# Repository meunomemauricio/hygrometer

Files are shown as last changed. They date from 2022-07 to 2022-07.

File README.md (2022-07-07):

# Hygrometer

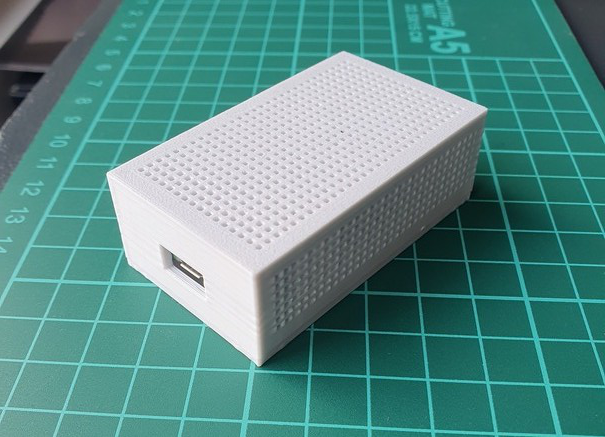
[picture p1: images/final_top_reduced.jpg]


DIY HA compatible Temperature & Humidity Sensor

# 3D Printed Enclosure

## Design

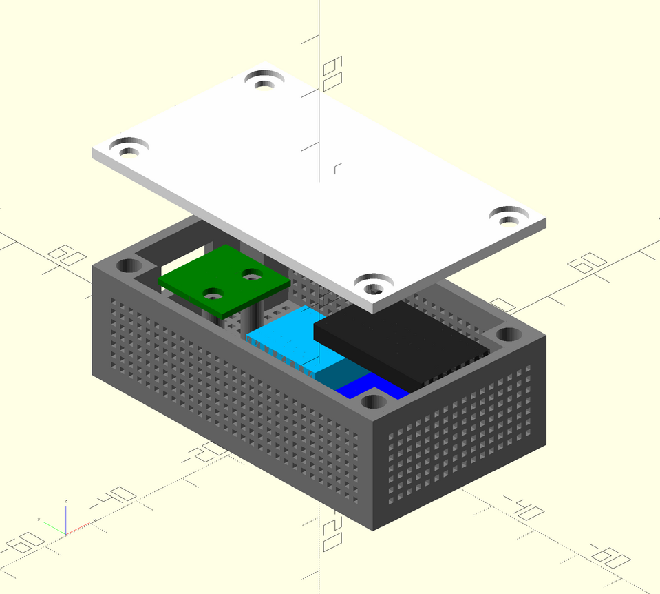
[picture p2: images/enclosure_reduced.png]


## USB Board 

It's better to test if the dimensions of the USB board are correct enough by printing a [simplified support](https://github.com/meunomemauricio/hygrometer/blob/f57ef0650a297ba861d08bb6003e8ca89dd94b08/usb_fit_test.scad).

| Simplified Support |  Board fit
:-------------------:|:-------------------------:
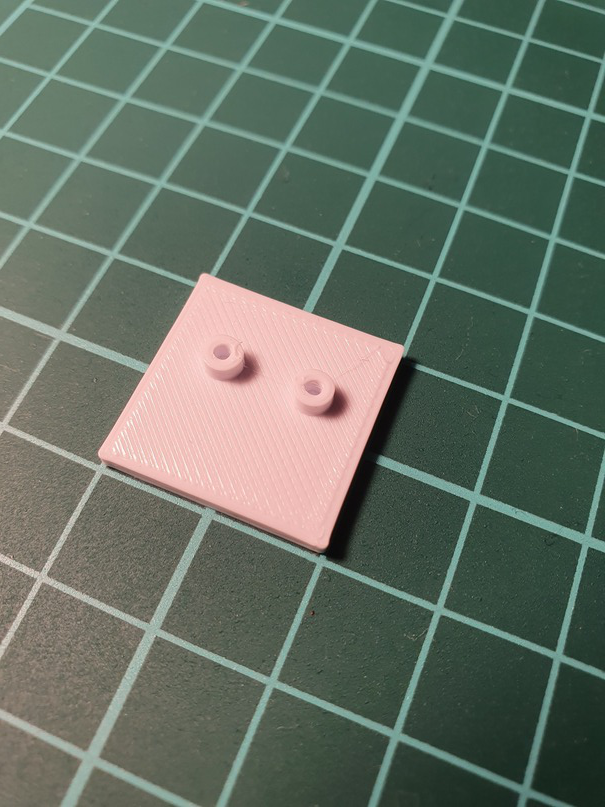
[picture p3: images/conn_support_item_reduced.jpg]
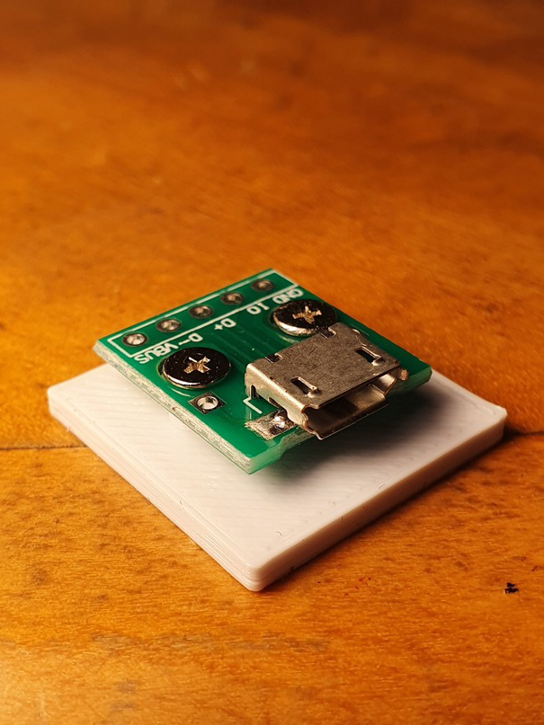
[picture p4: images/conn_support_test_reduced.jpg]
  |  

## Fit Test Print

Once I finished the enclosure design, I used the slicer to make a cut of the model that contain the main features.

| Items |  Fit Test
:-------------------:|:-------------------------:
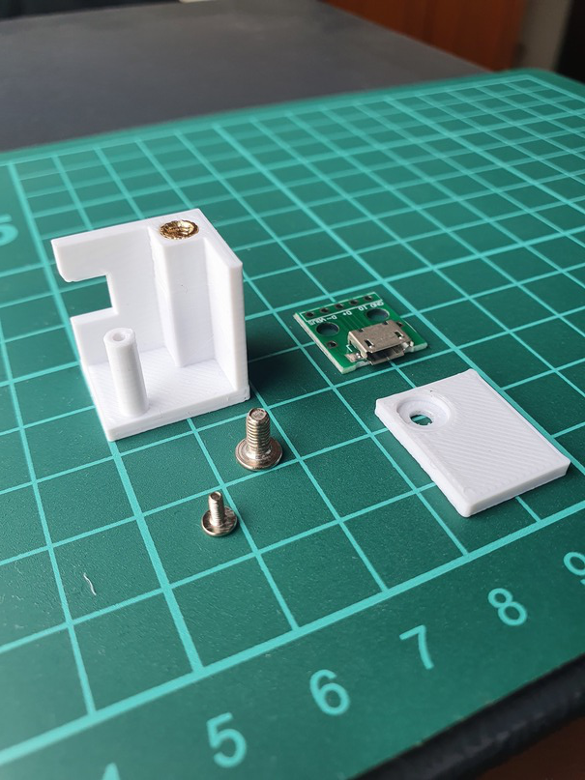
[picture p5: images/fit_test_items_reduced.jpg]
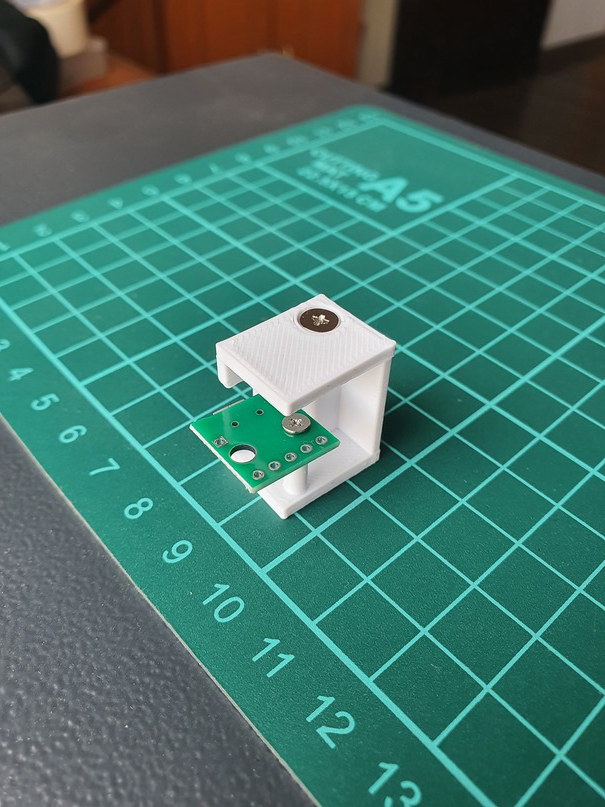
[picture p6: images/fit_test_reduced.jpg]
 | 

## Final Print and Assembly

The end result fit perfectly! Everything looks great, but there's a _very unfortunate problem_.

The simple mesh I created in the laterals is not enough to dissipate the heat from the voltage regulators. It raises the temperatures in the DHT11 significantly (~5C higher).

| Empty Enclosure |  Compoments | Closed Enclosure | Lateral Shot
:-------------------:|:-------------------------:|:-------------------------:|:-------------------------:
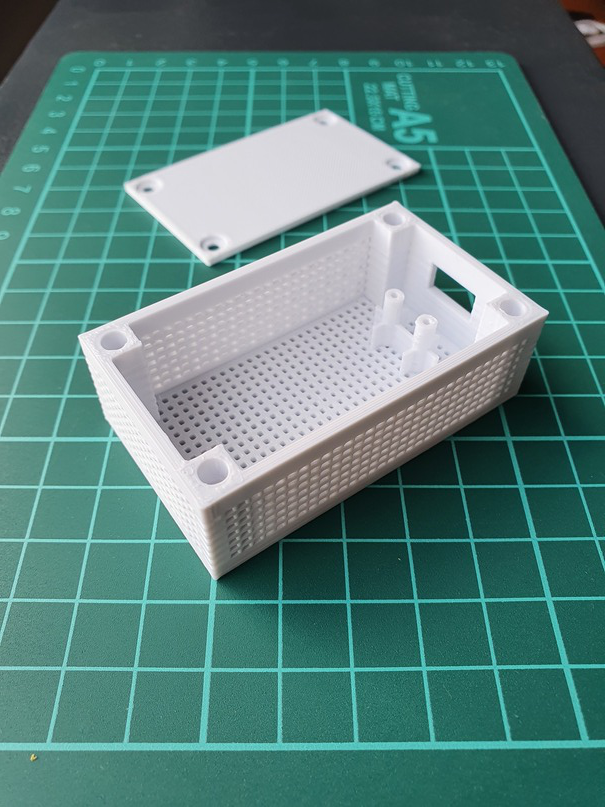
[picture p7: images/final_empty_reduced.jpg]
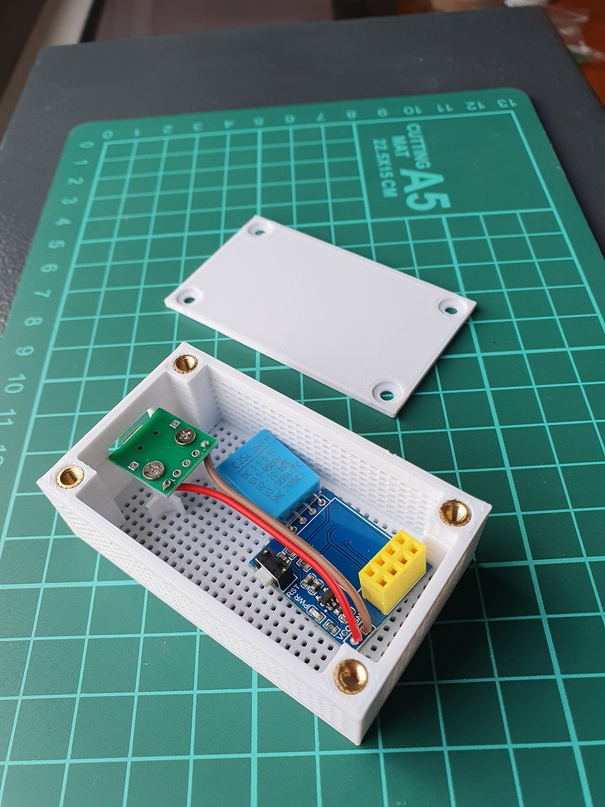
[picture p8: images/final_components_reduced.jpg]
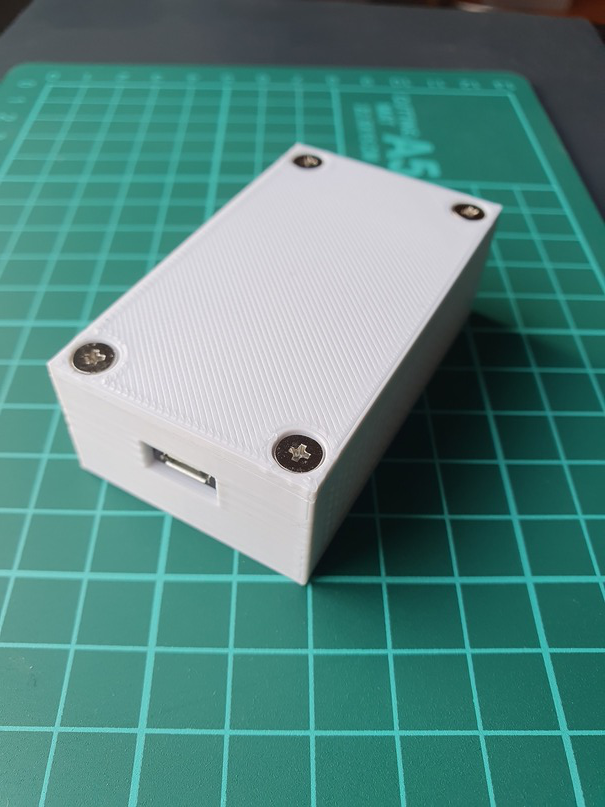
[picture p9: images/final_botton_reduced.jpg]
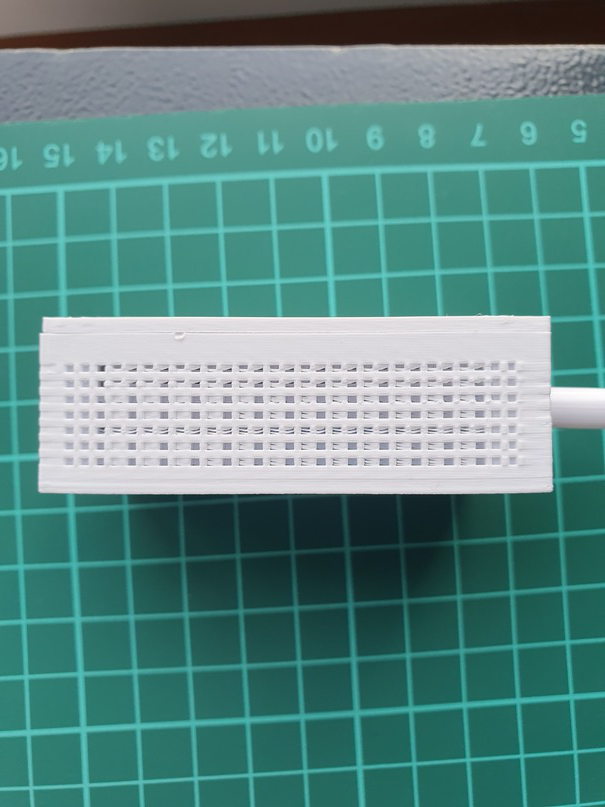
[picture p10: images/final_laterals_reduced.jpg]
 |  |  |

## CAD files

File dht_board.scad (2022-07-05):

// DHT Shield Board + ESP Board

include <dimensions.scad>

module dht_board() {
  // Board
  color("blue")
    cube([dht_board_w, dht_board_d, dht_board_h], center=true);

  // DHT Module
  color("deepskyblue")
    translate([dht_board_w/2-dht_w/2, dht_board_d/2+dht_d/2 + dht_d_of, dht_h/2 - dht_board_h/2])
    cube([dht_w, dht_d, dht_h], center=true);

  // ESP Connectors
  color("yellow")
    translate([
      dht_board_w/2-dht_conn_w/2 - dht_conn_w_of,
      -(dht_board_d/2-dht_conn_d/2),
      dht_conn_h/2 + dht_board_h/2
    ])
    cube([dht_conn_w, dht_conn_d, dht_conn_h], center=true);

  // Reset Button
  color("#222222") // Almost Black
    translate([
      -(dht_board_w/2 - dht_btn_w/2),
      dht_board_d/2 - dht_btn_d/2 - dht_btn_d_of,
      dht_board_h/2 + dht_btn_h/2
    ])
    cube([dht_btn_w, dht_btn_d, dht_btn_h], center=true);

  // ESP Board
  color("#222222") // Almost Black
    translate([
      dht_board_w/2 - esp_board_w/2 + esp_board_w_of,
      0,
      dht_board_h/2 + esp_board_h/2 + esp_conn_h + dht_conn_h
    ])
    cube([esp_board_w, esp_board_d, esp_board_h], center=true);
}

dht_board();

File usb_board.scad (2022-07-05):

// USB Connector Board

include <dimensions.scad>

module usb_board() {
  // Board
  color("green")
    difference() {
      cube([usb_board_w, usb_board_d, usb_board_h], center=true);

      translate([0, -((usb_board_d/2)-usb_hole_d_of), -usb_board_h]) {
        translate([usb_hole_w_of/2, 0, 0])
          cylinder(d=usb_hole_d, h=usb_board_h*2);

        translate([-usb_hole_w_of/2, 0, 0])
          cylinder(d=usb_hole_d, h=usb_board_h*2);
      }
    }

  // Connector
  color("grey")
    translate([0, usb_board_d/2 - usb_conn_d/2 + usb_conn_d_of, usb_board_h/2 + usb_conn_h/2])
    cube([usb_conn_w, usb_conn_d, usb_conn_h], center=true);
}

usb_board();

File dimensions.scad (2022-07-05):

// Dimensions (in mm)

// Minimal Clearance
_min_cl = 0.2;

// Enclosure

enc_w = 38;
enc_d = 65;
enc_h = 20.5;

enc_tk = 2;

// Enclosure Lid

lid_h = enc_tk;

// Lid Screw Holes

lid_hole_r = 3.2/2;  // M3 screws
lid_hole_h = lid_h * 1.2;

lid_pocket_r = 6.4 / 2;  // Screw Head Pocket
lid_pocket_h = 1.1;

// Screw Inserts

screw_ins_r = 4.2/2;
screw_ins_h = 6;

screw_ins_h_of = enc_h / 2 - screw_ins_h + _min_cl * 1.1;

// Screw Supports

screw_sup_w = screw_ins_r * 2 + 2.2;
screw_sup_d = screw_ins_r * 2 + 2.2;
screw_sup_h = enc_h - enc_tk;

screw_sup_w_of = enc_w/2 - screw_sup_w/2 - enc_tk + 1;
screw_sup_d_of = enc_d/2 - screw_sup_d/2 - enc_tk + 1;
screw_sup_h_of = enc_tk/2;

// Enclosure Mesh

enc_mesh_tk = 1;

// ESP Board

esp_board_w = 15;     // 14.78
esp_board_d = 25;     // 24.60
esp_board_h = 3;      // 3.14
esp_board_w_of = 0.4; // Not measured

esp_conn_h = 2.9; // 2.90

// DHT Board

dht_board_w = 21;  // 20.90
dht_board_d = 26;  // 25.29
dht_board_h = 1.6; // 1.61

dht_enc_d_of = -(enc_d / 2 - dht_board_d / 2) + enc_tk + 2;  // Distance from the enclosure
dht_enc_h_of = enc_tk + 1.5;

dht_conn_w = 11;     // 10.52
dht_conn_d = 5;      // 4.93
dht_conn_h = 9;      // 8.88
dht_conn_w_of = 1.5; // 11.54

dht_w = 13;     // 12.54
dht_d = 16;     // 16.20
dht_h = 6;      // 6.01
dht_d_of = 0.8; // Offset from DHT module and board

// TODO: Validate dimensions
dht_slot_w = dht_w;
dht_slot_d = dht_d;
dht_slot_h = enc_tk + _min_cl * 2;

dht_slot_w_of = 4;  // Make dependent
dht_slot_d_of = 6.3;  // Make dependent
dht_slot_h_of = -enc_h / 2 + enc_tk / 2;

dht_btn_w = 3;      // 3.33
dht_btn_d = 6;      // 6.06
dht_btn_h = 3;      // 2.99
dht_btn_d_of = 1.8; // 1.84

// USB Board

usb_board_w = 15;  // 14.48
usb_board_d = 15;  // 14.85
usb_board_h = 1.1; // 1.10

// Distance from the enclosure
usb_enc_d_of = enc_d / 2 - usb_board_d / 2 - enc_tk - .4;
usb_enc_h_of = enc_tk + 12;

usb_conn_w = 7.3;  // 7.30
usb_conn_d = 5.3;  // 5.26
usb_conn_h = 2.3;  // 2.32
usb_conn_d_of = 1; // 1.02

usb_hole_d = 3.5;    // 3.48
usb_hole_w_of = 8.5; // 8.45 - Between the holes. Assuming they're centered.
usb_hole_d_of = 5.5; // 5.50 - From oposite side of USB connector

usb_sup_base_d = 3.7;
usb_sup_base_h = usb_enc_h_of - enc_tk - usb_board_h / 2;

usb_sup_hole_d = 1.4 * 1.1;  // For M1.6 screws, 110% tolerance
usb_sup_hole_h = usb_sup_base_h / 2;

usb_sup_base_w_of = usb_hole_w_of / 2 ;
usb_sup_base_d_of = usb_enc_d_of - enc_tk; // From lid center
usb_sup_base_h_of = -enc_h / 2 + enc_tk;

usb_slot_w = usb_conn_w + 4;
usb_slot_d = enc_tk + _min_cl *2;
usb_slot_h = usb_conn_h + 4;

usb_slot_w_of = 0;
usb_slot_d_of = enc_d / 2 - usb_slot_d / 2 + _min_cl;
usb_slot_h_of = -enc_h / 2 + enc_tk + usb_sup_base_h - usb_conn_h / 2;

usb_sup_rein_tk = .8;

usb_sup_rein_w = usb_hole_w_of * 2;
usb_sup_rein_d = usb_hole_w_of;
usb_sup_rein_h = usb_sup_base_h / 2;

usb_sup_rein_w_of = usb_hole_w_of / 2;
usb_sup_rein_d_of = usb_sup_base_d_of;
usb_sup_rein_h_of = usb_sup_base_h_of + usb_sup_rein_h / 2;

usb_sup_hole_h_of = usb_sup_rein_h + _min_cl;

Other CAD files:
enclosure.scad
usb_fit_test.scad

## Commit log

2022-05-27 Model USB board
    [enclosure.scad]
2022-05-27 Model the DHT and ESP boards
    [enclosure.scad]
2022-05-30 Add USB board support fit test
    [enclosure.scad]
2022-05-30 Add USB board test images to README
2022-05-30 Add link to USB board test to README
2022-06-01 Create base enclosure
    [enclosure.scad]
2022-06-01 Add USB slot
    [enclosure.scad]
2022-06-01 Add DHT Slot
    [enclosure.scad]
2022-06-16 Add basic lid
    [enclosure.scad]
2022-06-16 Reorganize in multiple files
    [dht_board.scad, dimensions.scad, enclosure.scad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]
2022-06-16 Add USB supports on lid
    [dht_board.scad, dimensions.scad, enclosure.scad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]
2022-07-01 Fix USB support height
    [dimensions.scad, enclosure.scad]
2022-07-01 Add screw insert supports
    [dimensions.scad, enclosure.scad]
2022-07-01 Add Lid Screw Holes
    [dimensions.scad, enclosure.scad]
2022-07-04 Adjust dimensions after test print
    [dimensions.scad, enclosure.scad]
2022-07-04 Move USB support to enclosure
    [dimensions.scad, enclosure.scad]
2022-07-04 Lower USB board
    [dimensions.scad, enclosure.scad]
2022-07-04 Adjust enclusure height
    [dimensions.scad, enclosure.scad]
2022-07-04 Add lid screw guides
    [enclosure.scad]
2022-07-05 Cut a mesh from the enclosure laterals
    [dimensions.scad, enclosure.scad]
2022-07-05 Add enclosure design image to README
2022-07-05 Reinforce USB support
    [dht_board.scad, dimensions.scad, enclosure.scad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]
2022-07-05 Bring USB board closer to enclosure
    [dimensions.scad]
